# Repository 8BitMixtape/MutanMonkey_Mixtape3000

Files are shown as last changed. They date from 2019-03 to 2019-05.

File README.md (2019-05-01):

# MixtapeNEO-3000
It's not really new... but finally fully working wiht KiCAD and svg2Shenzhen.
Reworked the "classic" 8Bit Mixtape NEO, now with new design, working amplifier 8002 and integrated speaker.
This special editiom was designed for the Workshop in Barcelona:
http://wiki.8bitmixtape.cc/#/1_10-MutanMonkey-BCN

## Fully assembled version

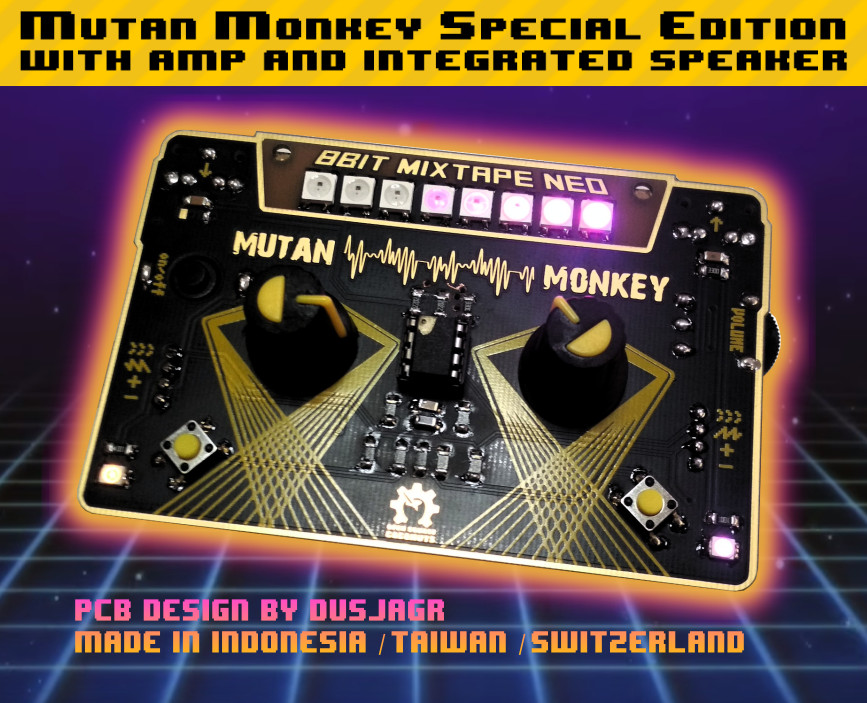
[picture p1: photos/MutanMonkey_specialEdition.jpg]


Now also available in the [8Bit Mixtape Shop](http://shop.8bitmixtape.cc/product/mutan-monkey-limited-edition-8bit-mixtape-neo-premade/ "Go to Shop")

## KiCAD PCB and 3d View

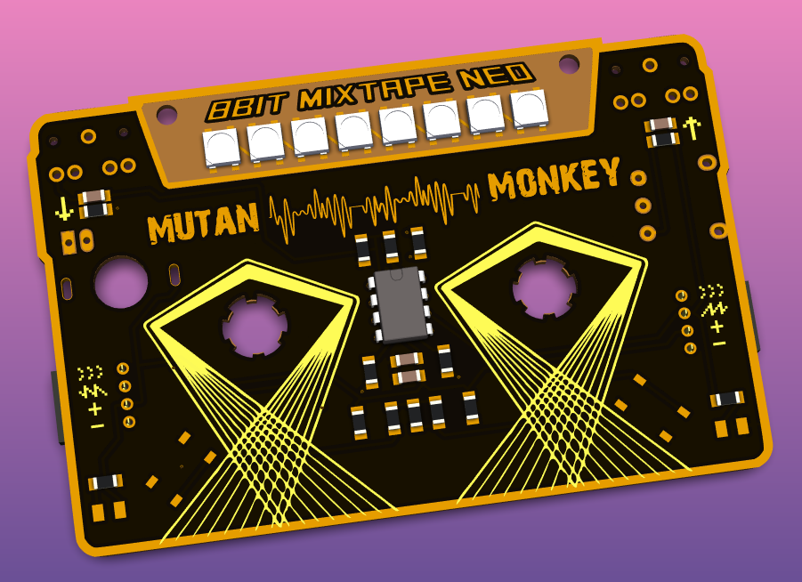
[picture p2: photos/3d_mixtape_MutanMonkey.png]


## KiCAD complete schematic

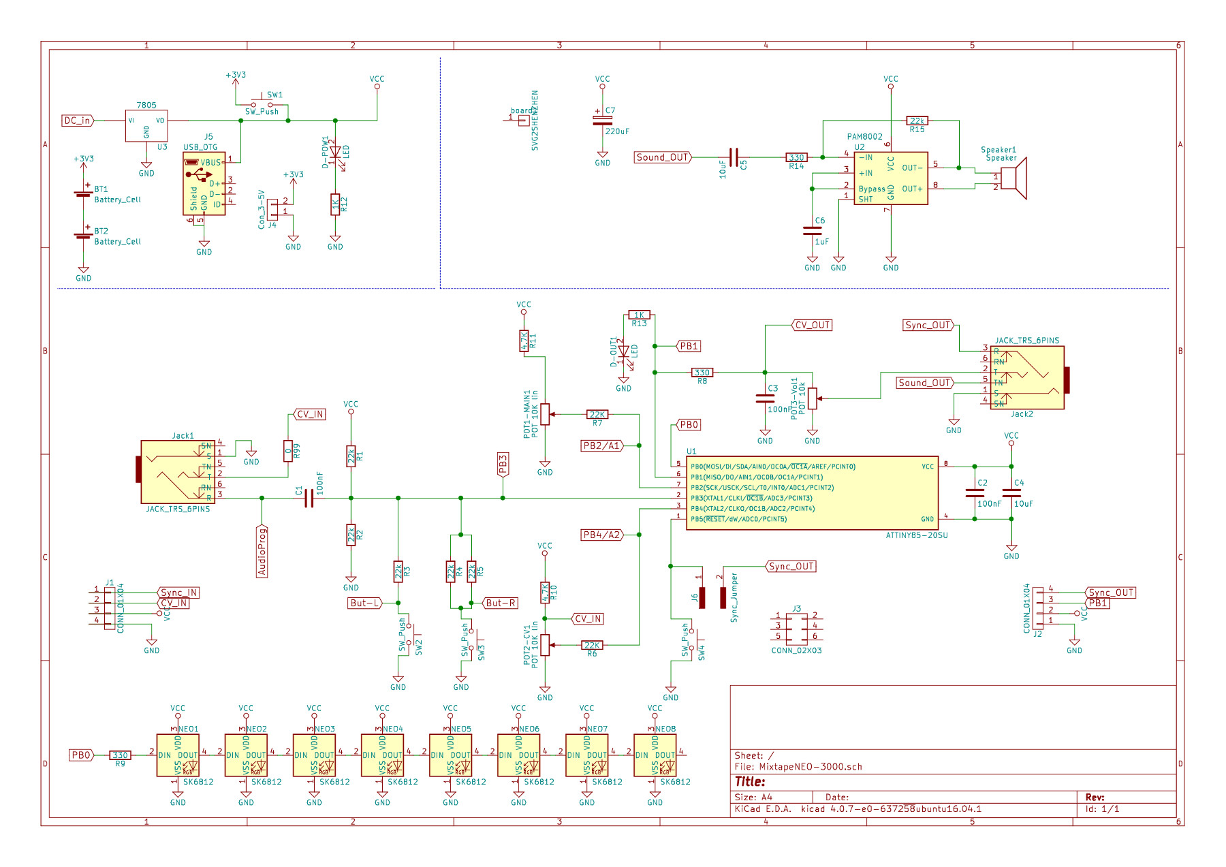
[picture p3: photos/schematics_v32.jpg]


## creative design layer in Inkscape with svg2shenzhen extension

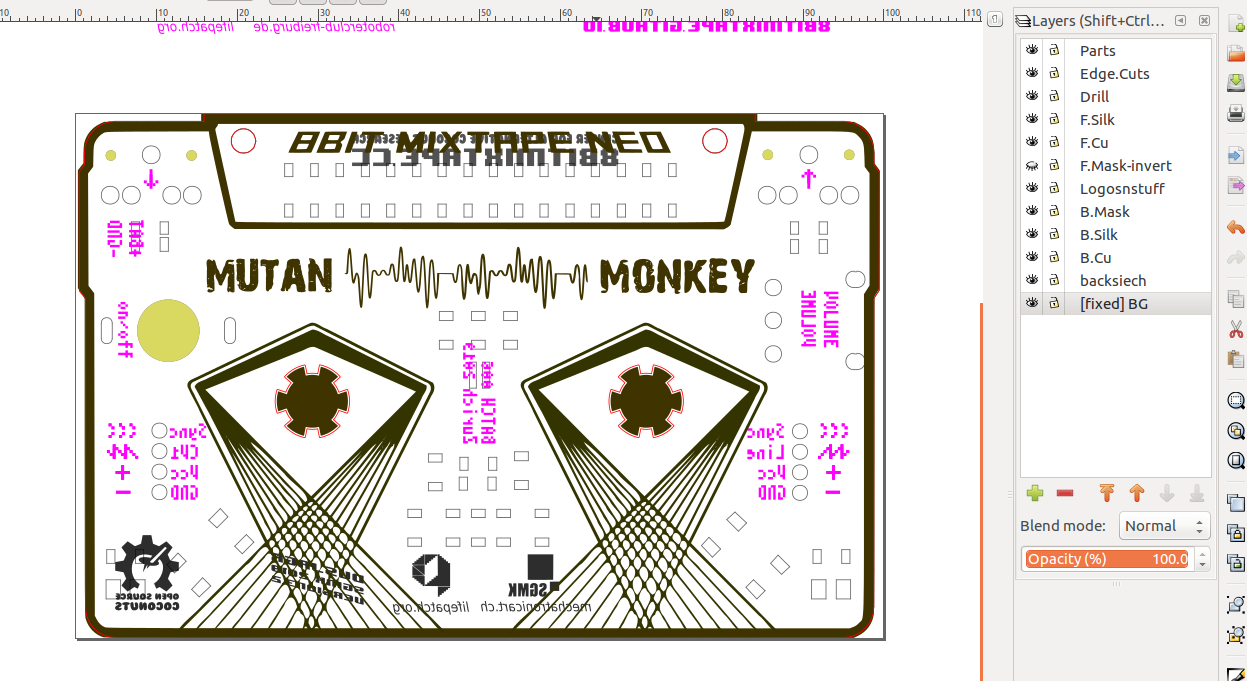
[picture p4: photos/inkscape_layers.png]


See more about svg2shenzhen here: https://github.com/badgeek/svg2shenzhen

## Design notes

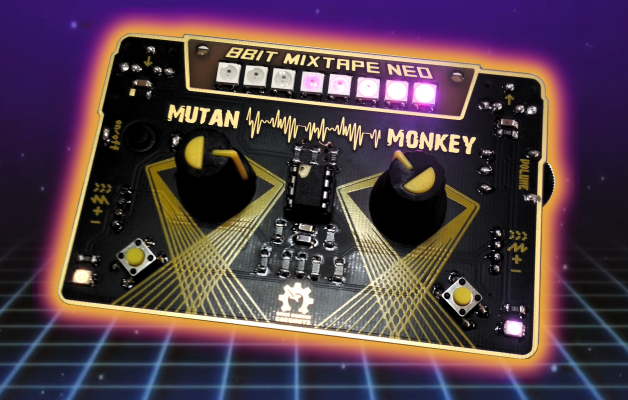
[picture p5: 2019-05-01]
photos/MutanMonkey_specialEdition_space.png

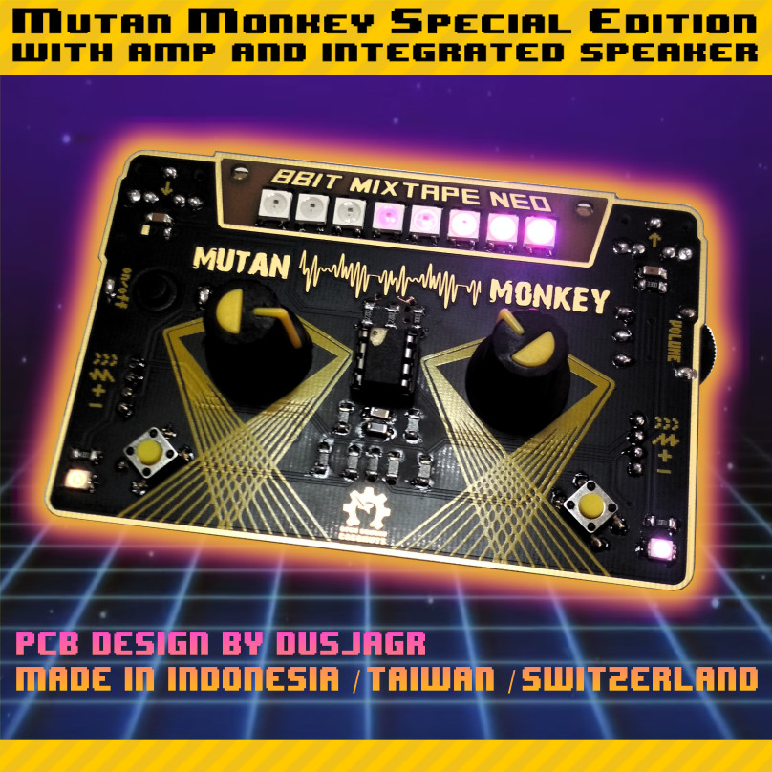
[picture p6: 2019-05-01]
photos/MutanMonkey_specialEdition_sq.jpg

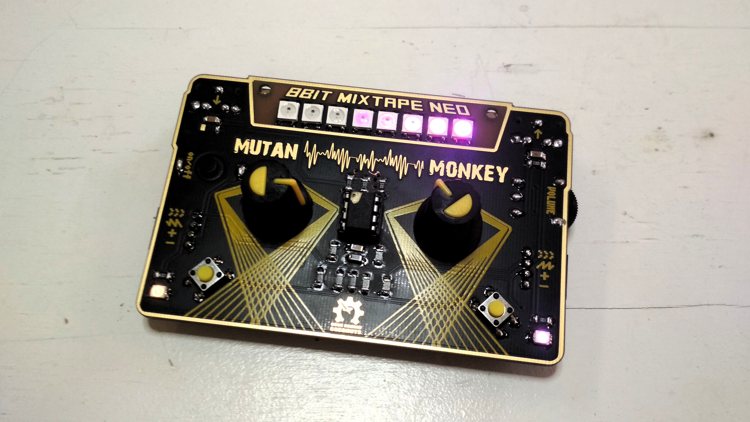
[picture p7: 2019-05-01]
photos/MutanMonkey_mixtape.jpg

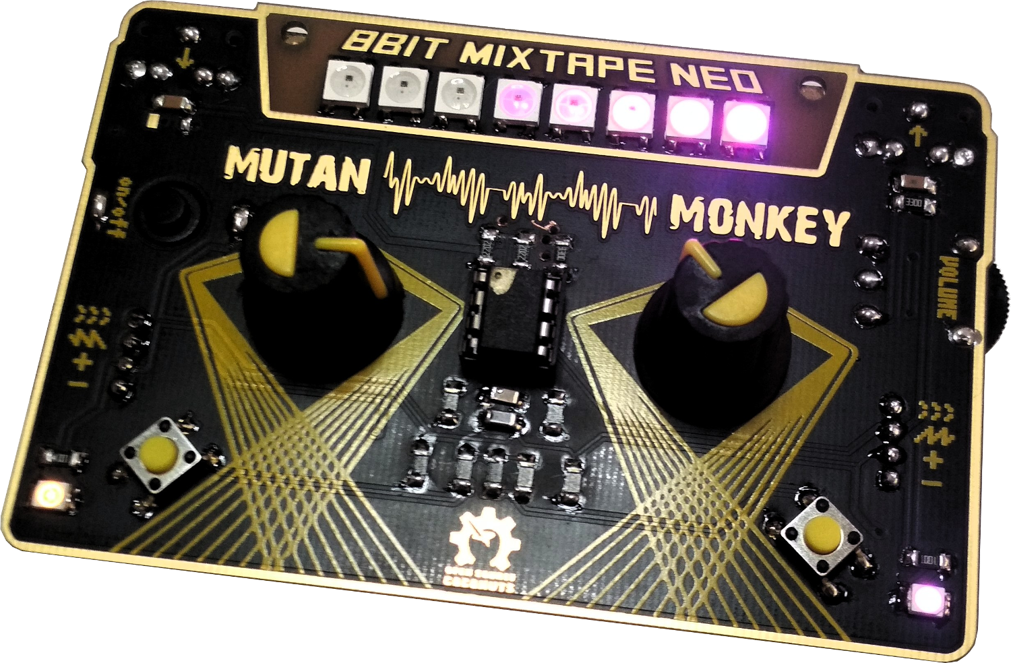
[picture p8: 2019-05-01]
photos/MutanMonkey_mixtape_trans.png

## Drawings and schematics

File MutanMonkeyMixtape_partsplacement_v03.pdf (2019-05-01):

C1 | C2

R3R4

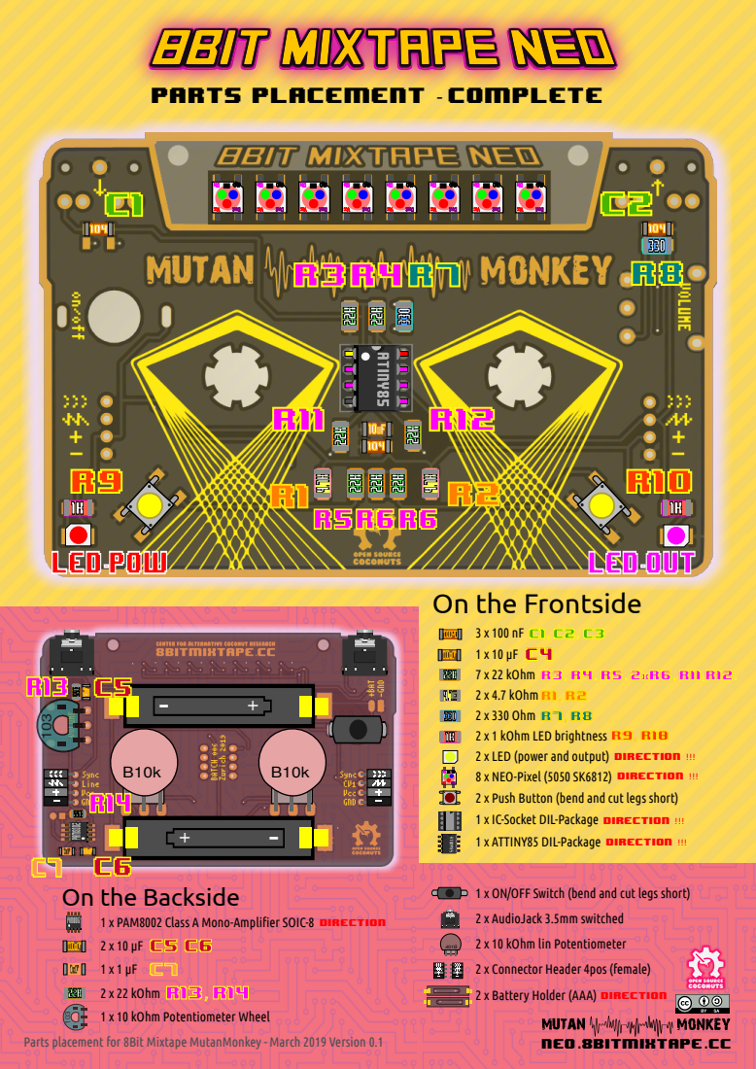
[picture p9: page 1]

2 x LED (power and output) direction !!!

2 x Push Button (bend and cut legs short)
1 x IC-Socket DIL-Package direction !!!
1 x ATTINY85 DIL-Package direction !!!

1 x ON/OFF Switch (bend and cut legs short)
2 x AudioJack 3.5mm switched

1 x PAM8002 Class A Mono-Amplifier SOIC-8
1 x 10 kOhm Potentiometer Wheel

Parts placement for 8Bit Mixtape MutanMonkey - March 2019 Version 0.1

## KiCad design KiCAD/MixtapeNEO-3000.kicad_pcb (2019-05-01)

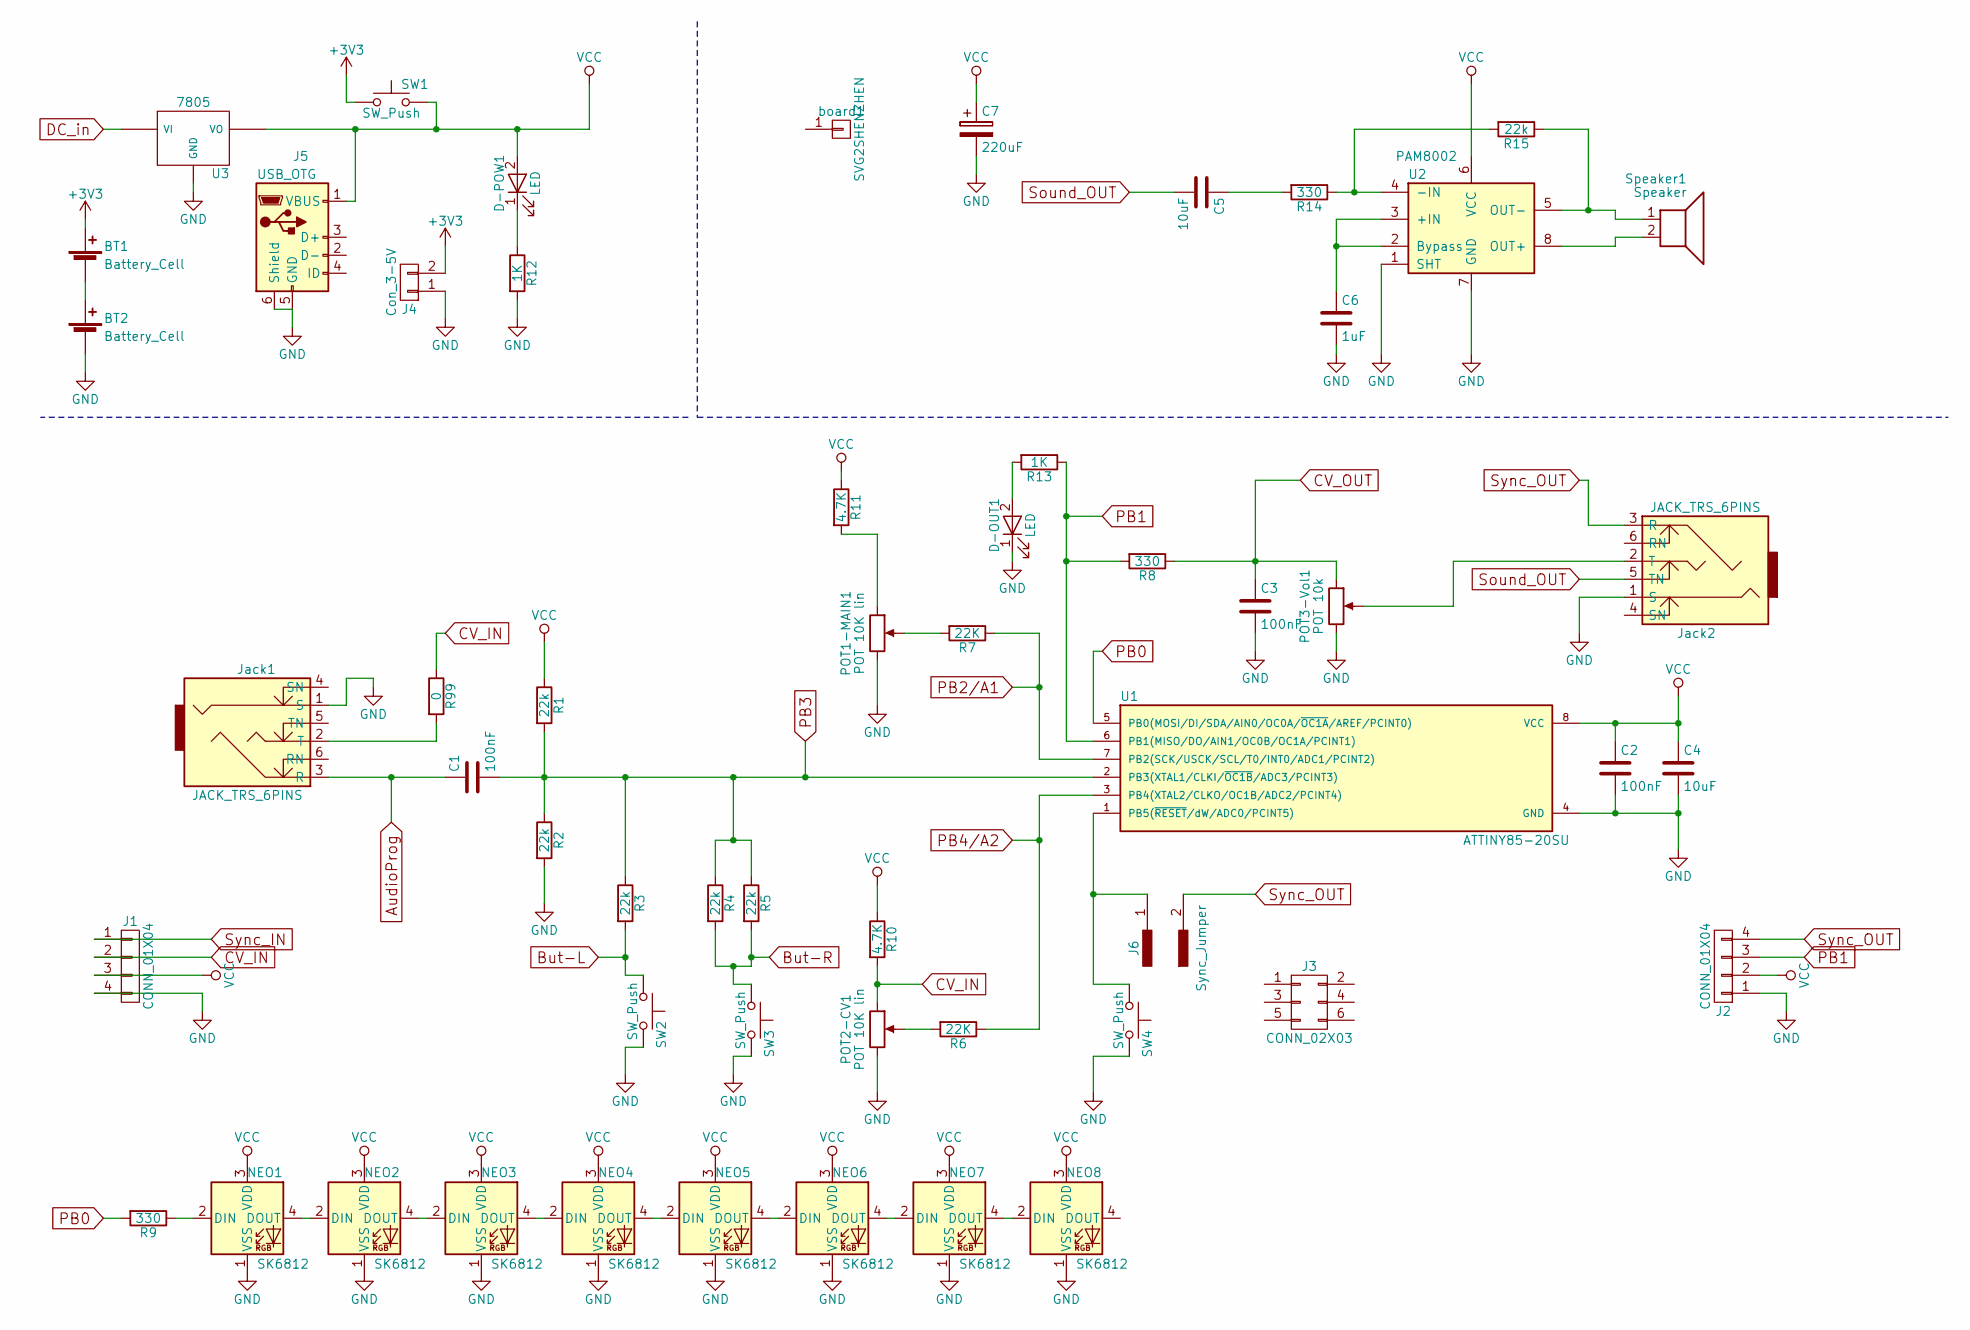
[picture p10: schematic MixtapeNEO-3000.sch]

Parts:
BT1, BT2: Battery_Cell; BAT_Holder_AAA-new_noHole
C1, C2, C3: 100nF; C_1206_HandSoldering
C4, C5: 10uF; C_1206_HandSoldering
C6: 1uF; C_1206_HandSoldering
C7: 220uF; C_1206_HandSoldering
D-OUT1: LED; LED_2835_minimal
D-POW1: LED; LED_2835_minimal
J1, J2: CONN_01X04; Angled_1x04_Pitch2.54mm-flip
J3: CONN_02X03; Socket_Strip_Straight_2x03_Pitch2.54mm
J4: Con_3-5V; Bat_connector_SMD
J5: USB_OTG; USB_Micro-B
J6: Sync_Jumper; Sync_jumper
Jack1, Jack2: JACK_TRS_6PINS; AUDIO-Jack_3.5mm_5Pin
NEO1, NEO2, NEO3, NEO4, NEO5, NEO6, NEO7, NEO8: SK6812; Mixtape_NEO_WS2812B
POT1-MAIN1, POT2-CV1: POT 10K lin; Potentiometer_backPads_noHole
POT3-Vol1: POT 10k; Potentiometer_wheel
R1, R2, R3, R4, R5, R15: 22k; R_1206_HandSoldering
R6, R7: 22K; R_1206_HandSoldering
R8, R9, R14: 330; R_1206_HandSoldering
R10, R11: 4.7K; R_1206_HandSoldering
R12, R13: 1K; R_1206_HandSoldering
R99: 0; R_1206_HandSoldering
SW1: SW_Push; Push_SWITCH_hole
SW2, SW3: SW_Push; TACTILE-PTH_6mm_SMD
SW4: SW_Push; SW_SPST_FSMSM
Speaker1: Speaker; SpeakerPads_SMD
U1: ATTINY85-20SU; Attiny_DIP-8_W7.62mm_mod
U2: PAM8002; SO-8_5.3x6.2mm_Pitch1.27mm
U3: 7805; TO-252-3_TabPin2
board1: SVG2SHENZHEN; MixtapeNEO-3000

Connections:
+3V3: BT1.1 (+), J4.2, SW1.1
AudioProg: C1.1, Jack1.3 (R)
But-L: R3.2, SW2.1
But-R: R4.2, R5.2, SW3.1
CV_IN: J1.2, POT2-CV1.1, R10.2, R99.1
CV_OUT: C3.1, POT3-Vol1.1, R8.1
GND: BT2.2 (-), C2.2, C3.2, C4.2, C6.2, C7.2, D-OUT1.1 (K), J1.4, J2.1, J4.1, J5.5 (GND), J5.6 (Shield), Jack1.1 (S), Jack2.1 (S), NEO1.1 (VSS), NEO2.1 (VSS), NEO3.1 (VSS), NEO4.1 (VSS), NEO5.1 (VSS), NEO6.1 (VSS), NEO7.1 (VSS), NEO8.1 (VSS), POT1-MAIN1.3, POT2-CV1.3, POT3-Vol1.3, R2.2, R12.2, SW2.2, SW3.2, SW4.2, U1.4 (GND), U2.1 (SHT), U2.7 (GND), U3.GND
unnamed: BT1.2 (-), BT2.1 (+)
unnamed: C5.1, R14.2
unnamed: C6.1, U2.2 (Bypass), U2.3 (+IN)
unnamed: D-OUT1.2 (A), R13.2
unnamed: D-POW1.1 (K), R12.1
unnamed: J6.1, SW4.1, U1.1 (PB5(~RESET~/dW/ADC0/PCINT5))
unnamed: Jack1.2 (T), R99.2
unnamed: Jack2.2 (T), POT3-Vol1.2
unnamed: NEO1.2 (DIN), R9.1
unnamed: NEO1.4 (DOUT), NEO2.2 (DIN)
unnamed: NEO2.4 (DOUT), NEO3.2 (DIN)
unnamed: NEO3.4 (DOUT), NEO4.2 (DIN)
unnamed: NEO4.4 (DOUT), NEO5.2 (DIN)
unnamed: NEO5.4 (DOUT), NEO6.2 (DIN)
unnamed: NEO6.4 (DOUT), NEO7.2 (DIN)
unnamed: NEO7.4 (DOUT), NEO8.2 (DIN)
unnamed: POT1-MAIN1.1, R11.2
unnamed: POT1-MAIN1.2, R7.2
unnamed: POT2-CV1.2, R6.2
unnamed: R14.1, R15.2, U2.4 (-IN)
unnamed: R15.1, Speaker1.1, U2.5 (OUT-)
unnamed: Speaker1.2, U2.8 (OUT+)
PB0: R9.2, U1.5 (PB0(MOSI/DI/SDA/AIN0/OC0A/~OC1A~/AREF/P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)
PB1: J2.3, R8.2, R13.1, U1.6 (PB1(MISO/DO/AIN1/OC0B/OC1A/PCINT1))
PB2/A1: R7.1, U1.7 (PB2(SCK/USCK/SCL/T0/INT0/ADC1/PCINT2))
PB3: C1.2, R1.2, R2.1, R3.1, R4.1, R5.1, U1.2 (PB3(XTAL1/CLKI/~OC1B~/ADC3/PCINT3))
PB4/A2: R6.1, U1.3 (PB4(XTAL2/CLKO/OC1B/ADC2/PCINT4))
Sound_OUT: C5.2, Jack2.5 (TN)
Sync_OUT: J2.4, J6.2, Jack2.3 (R)
VCC: C2.1, C4.1, C7.1, D-POW1.2 (A), J1.3, J2.2, J5.1 (VBUS), NEO1.3 (VDD), NEO2.3 (VDD), NEO3.3 (VDD), NEO4.3 (VDD), NEO5.3 (VDD), NEO6.3 (VDD), NEO7.3 (VDD), NEO8.3 (VDD), R1.1, R10.1, R11.1, SW1.2, U1.8 (VCC), U2.6 (VCC), U3.VO

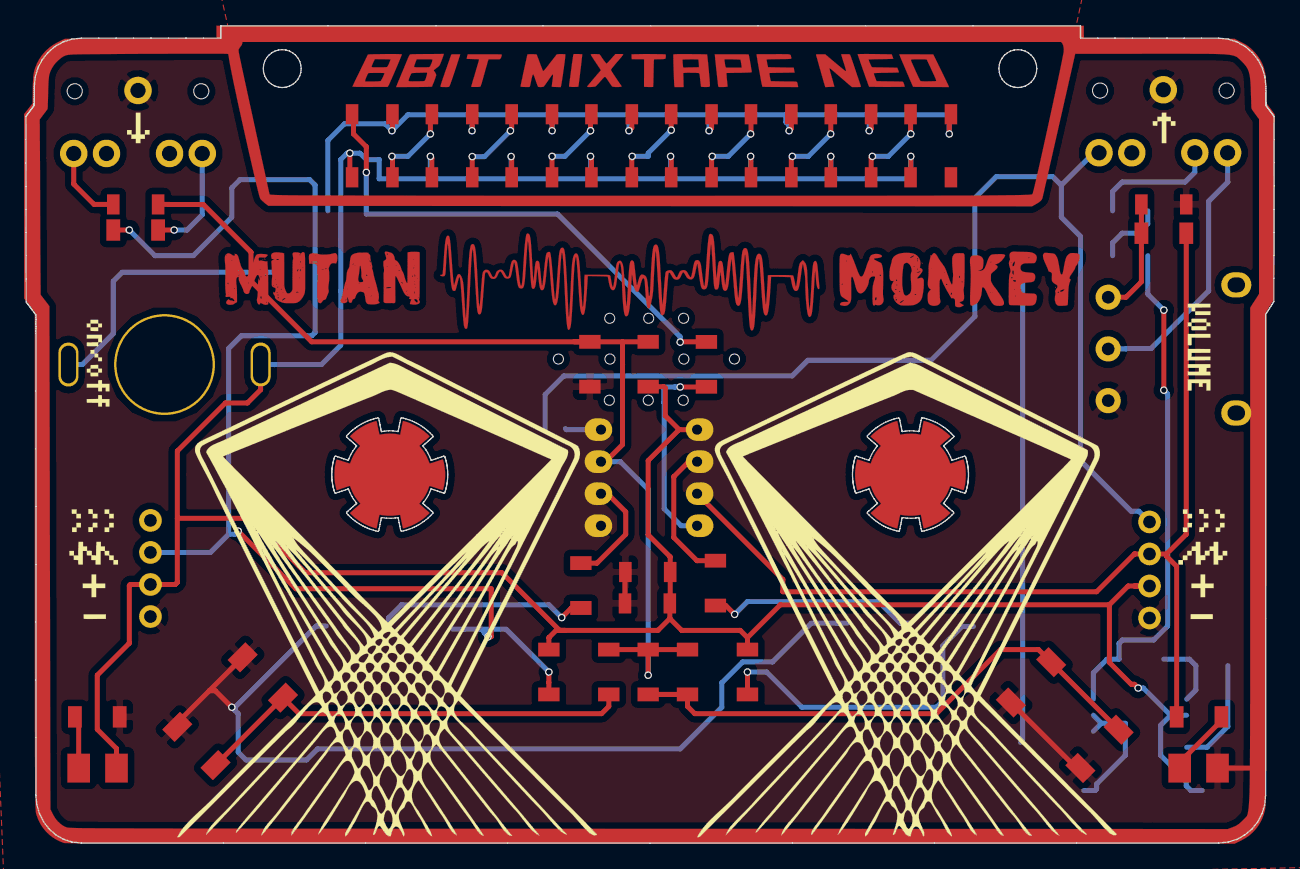
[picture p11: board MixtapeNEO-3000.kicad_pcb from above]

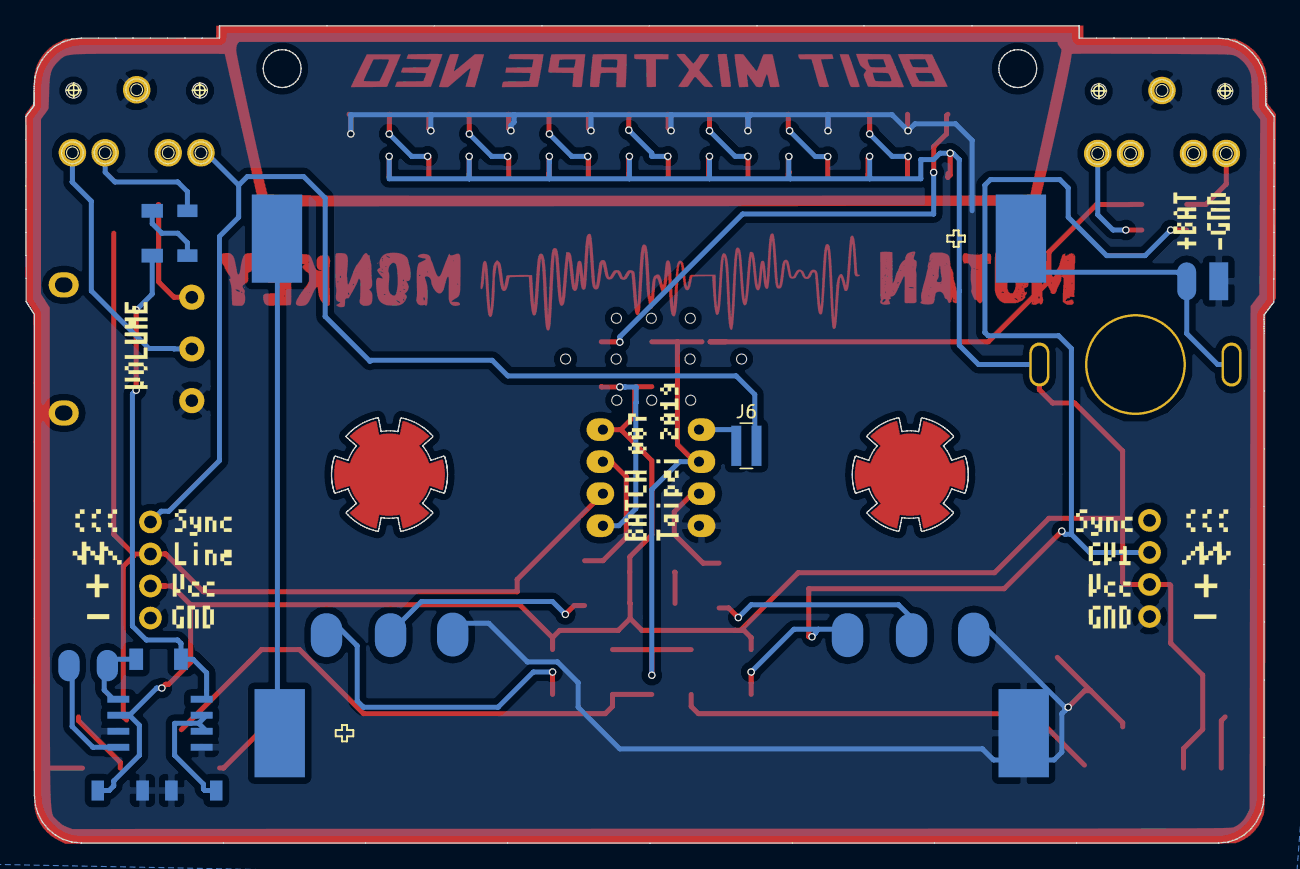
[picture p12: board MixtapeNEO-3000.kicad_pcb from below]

Board: 2 copper layers, 99.0 x 64.8 mm, 51 parts (16 on the bottom side), 37 nets.

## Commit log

2019-03-08 adding all files
    [MixtapeNEO-3000-B.Cu.gbr, MixtapeNEO-3000-B.Mask.gbr, MixtapeNEO-3000-B.SilkS.gbr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]
2019-05-01 revised version and photos
    [MixtapeNEO-3000-B.Cu.gbr, MixtapeNEO-3000-B.Mask.gbr, MixtapeNEO-3000-B.SilkS.gbr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]
2019-05-01 fixed board v3.3, incl dimplus special
    [MixtapeNEO-3000-B.Cu.gbr, MixtapeNEO-3000-B.Mask.gbr, MixtapeNEO-3000-B.SilkS.gbr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]
